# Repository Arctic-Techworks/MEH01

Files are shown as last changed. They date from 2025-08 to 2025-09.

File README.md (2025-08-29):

# **MEH01 replacement encoder for EVQWGD001**
 This is a very low cost (~ 1USD) full replacement for EVQWGD001 horizontal encoder. Project comes with all STL/STEP files for printing and incorporation into projects. It has the same base size as EVQWGD001 but due to different mounting mechanisms it won't "lock" into the EWQ* socket even though it fits. There are special openings in MEH01 socket where the encoder can "clip-in". 

Two versions are provided. With and without switch.

## **KiCAD** symbol, footprint and 3D model is also available (untested), check my [KiCad Library](https://github.com/EverydayErgo/KiCAD)

||||||
|--|--|--|--|--|
||
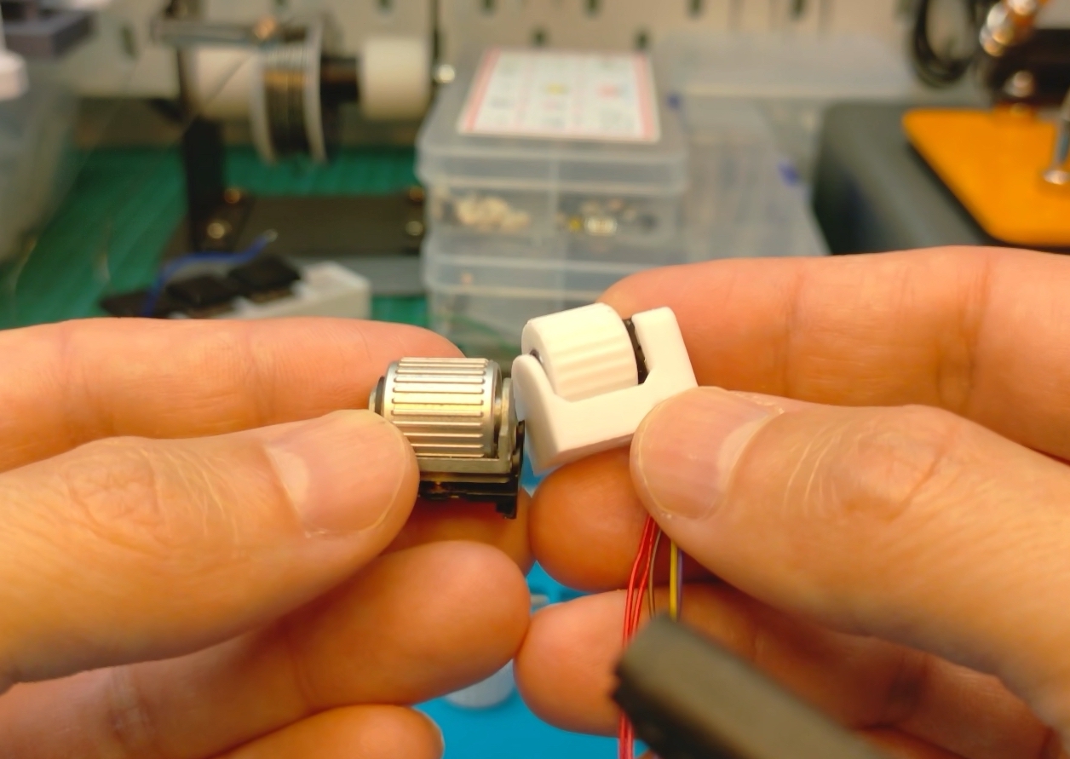
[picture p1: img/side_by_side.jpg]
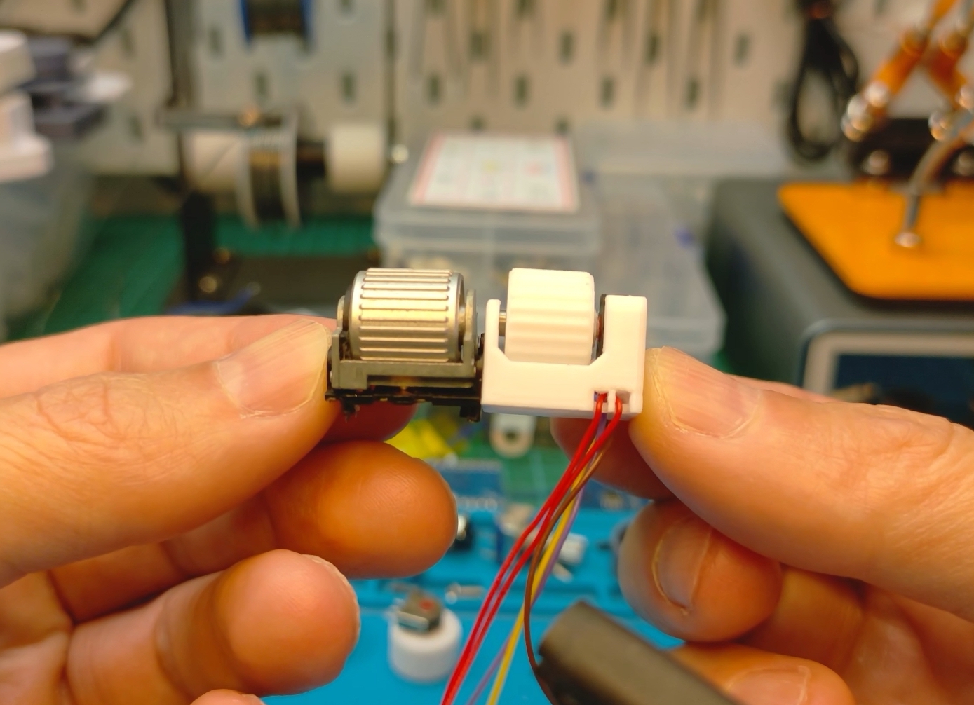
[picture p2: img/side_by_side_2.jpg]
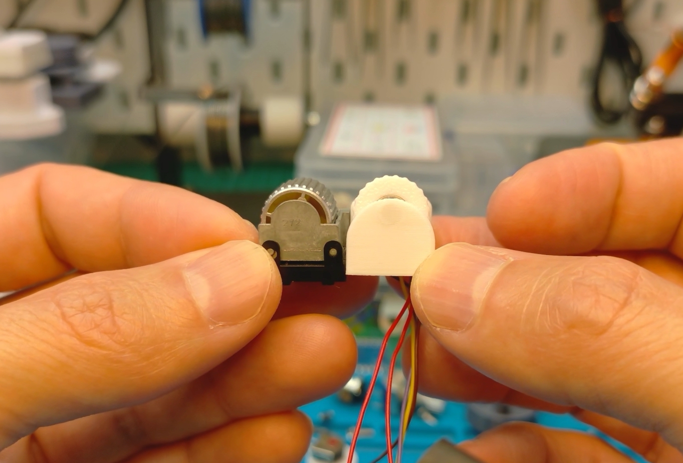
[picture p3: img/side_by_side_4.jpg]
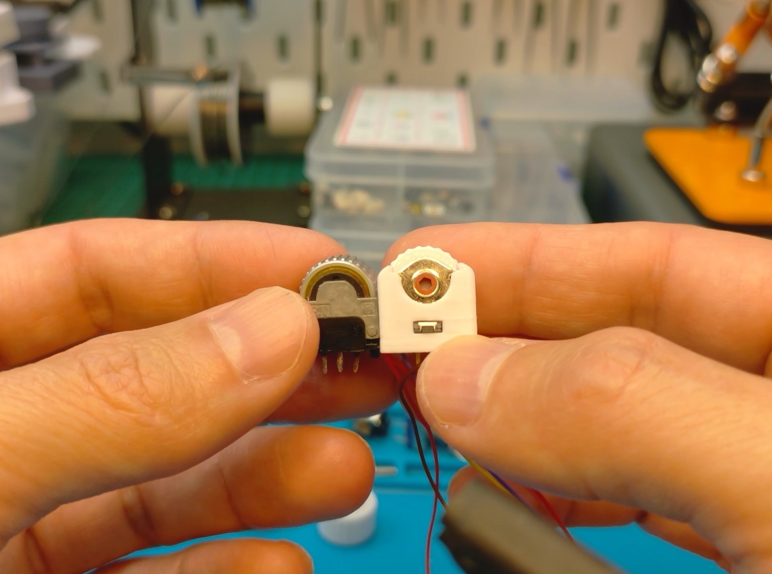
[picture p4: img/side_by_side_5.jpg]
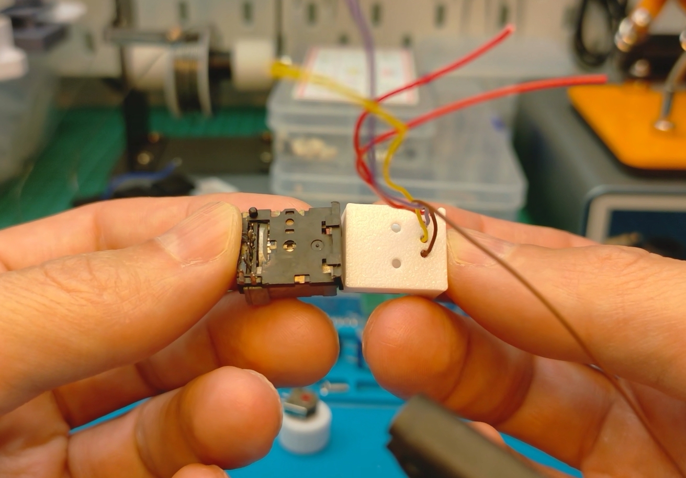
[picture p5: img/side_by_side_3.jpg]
||||||

|BOM|||
|--|--|--|
|**Item**|**Dimensions**|**Count**|
|[Kailh mouse encoder](img/kailh_1.png)|5mm|1|
|[MR63 RC Bearings (used in RC cars etc)](img/bearings_zzr.jpeg)|(M3)3mm x 6mm x 2mm|1|
|[Metal pin (bearing dowel)](img/metal_pin_1.jpg)|(M3)3mm x 6mm|1|
|[Tactile Push button](img/switch_1.jpg)|3mm x 4mm x 2mm|1|
|[AWG 30 Wire (best multi color)](img/wire_awg_30_1.jpg)||1|

Notice that the tactile switch has 1 leg, there's also version with 2 legs, this might be harder to solder wire to.

|STL||
|--|--|
|Item|Description|
|[Housing (switch)](stl/encoder_switch.stl)|Housing for the encoder with tactile switch|
|[Housing (no switch)](stl/encoder_no_switch.stl)|Housing for the encoder without switch|
|[Roller](stl/roller.stl)|Roller wheel|

**Print with PETG with 0.4mm nozzle. For the roller use support.**

|STEP||
|--|--|
|Item|Description|
|[Housing (switch)](step/encoder_switch.stp)|Housing for the encoder with tactile switch|
|[Housing (no switch)](step/encoder_no_switch.stp)|Housing for the encoder without switch|
|[Roller](step/roller.stp)|Roller wheel|
|[MEH01](step/MEH01.stp)|Full assembly|
|[Socket PCB](step/socket_pcb.stp)|Socket/mount for PCB|
|[Socket](step/socket.stp)|Socket/mount for keyboard plate|

Use these files to incorporate MEH01 into your CAD project.

## How to assemble
There are few live streams where I am building MEH01:
- [[Let's build #42] - Chordie, chording split mechanical keyboard you shouldn't be scared of
](https://youtu.be/GDPil8_5gyE?t=2537)
- [[Let's build #45] - Chordie, chording split mechanical keyboard you shouldn't be scared of
](https://youtu.be/FPBJ9f71gYo?t=291)

|||||
|--|--|--|--|
||
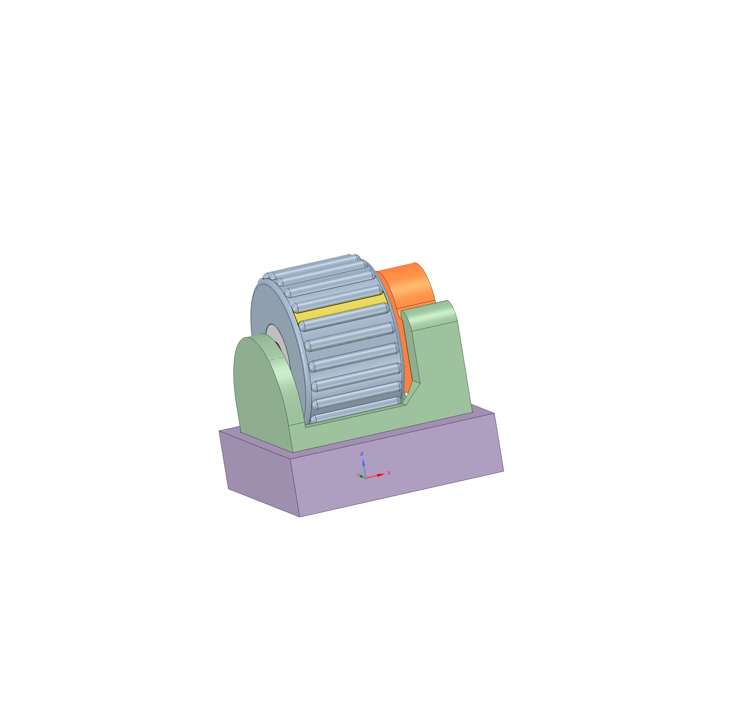
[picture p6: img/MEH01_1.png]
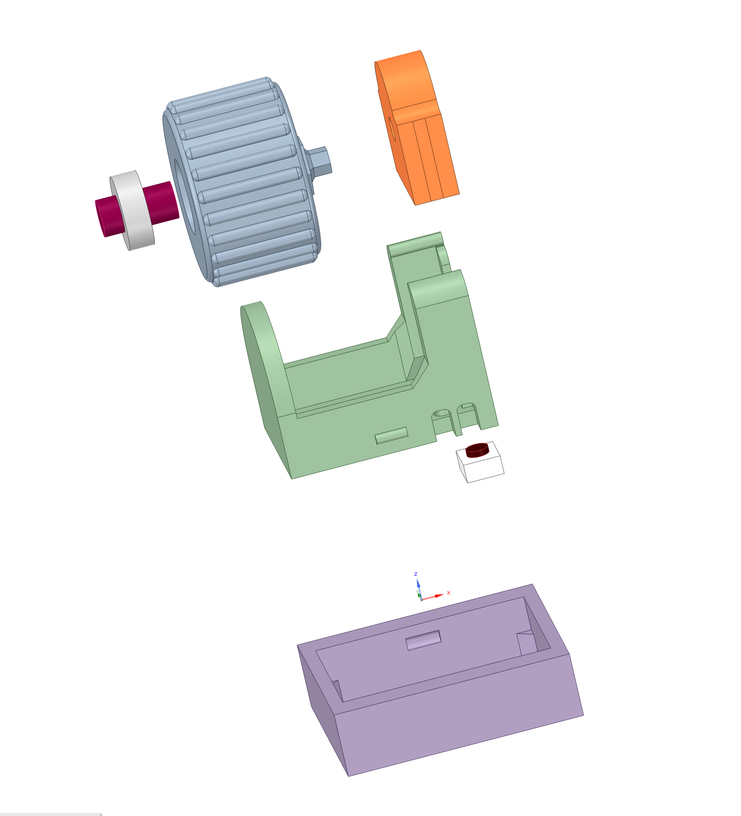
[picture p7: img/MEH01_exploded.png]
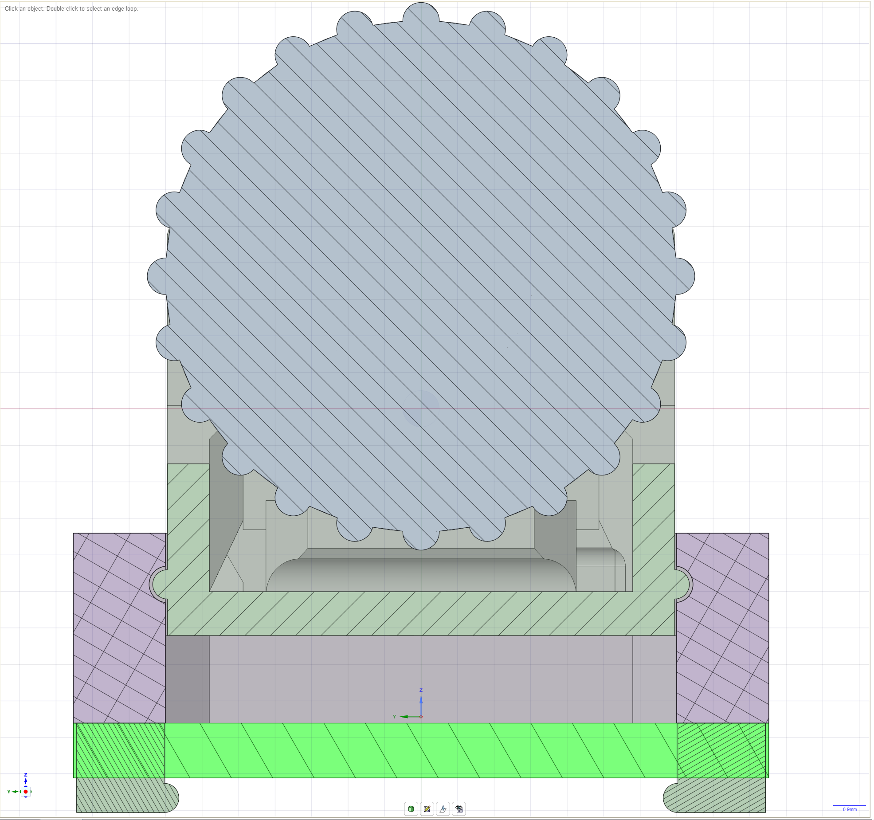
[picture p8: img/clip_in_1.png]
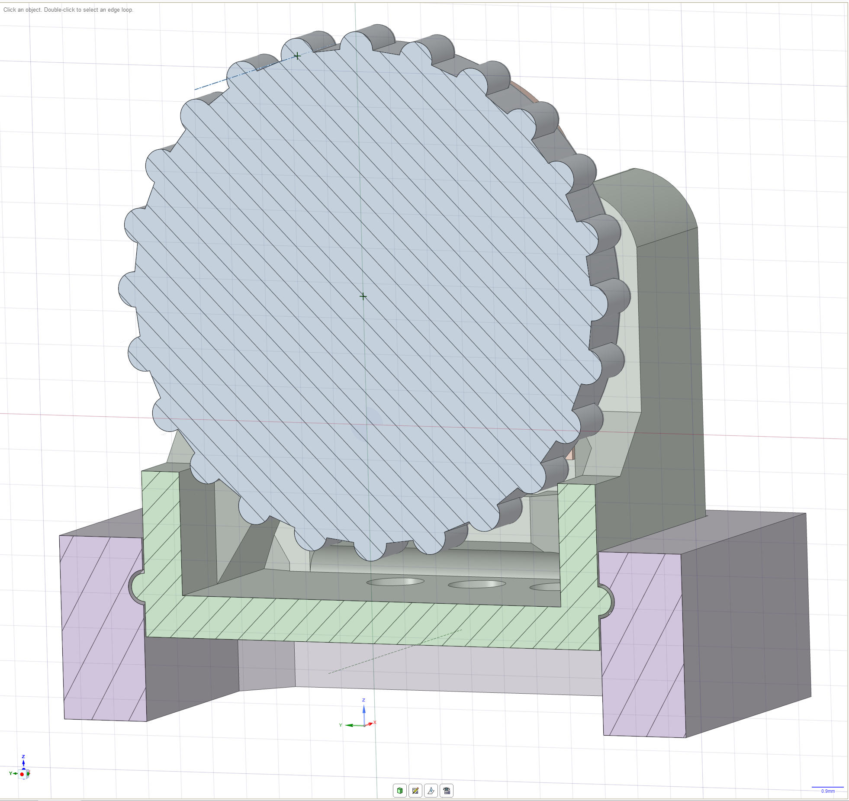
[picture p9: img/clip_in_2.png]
|||||

For the version with tactile switch, solder AWG 30 wire to the switch terminals and route it. There's a canal under the switch to route left terminal, both should go via two holes on the side of the housing.

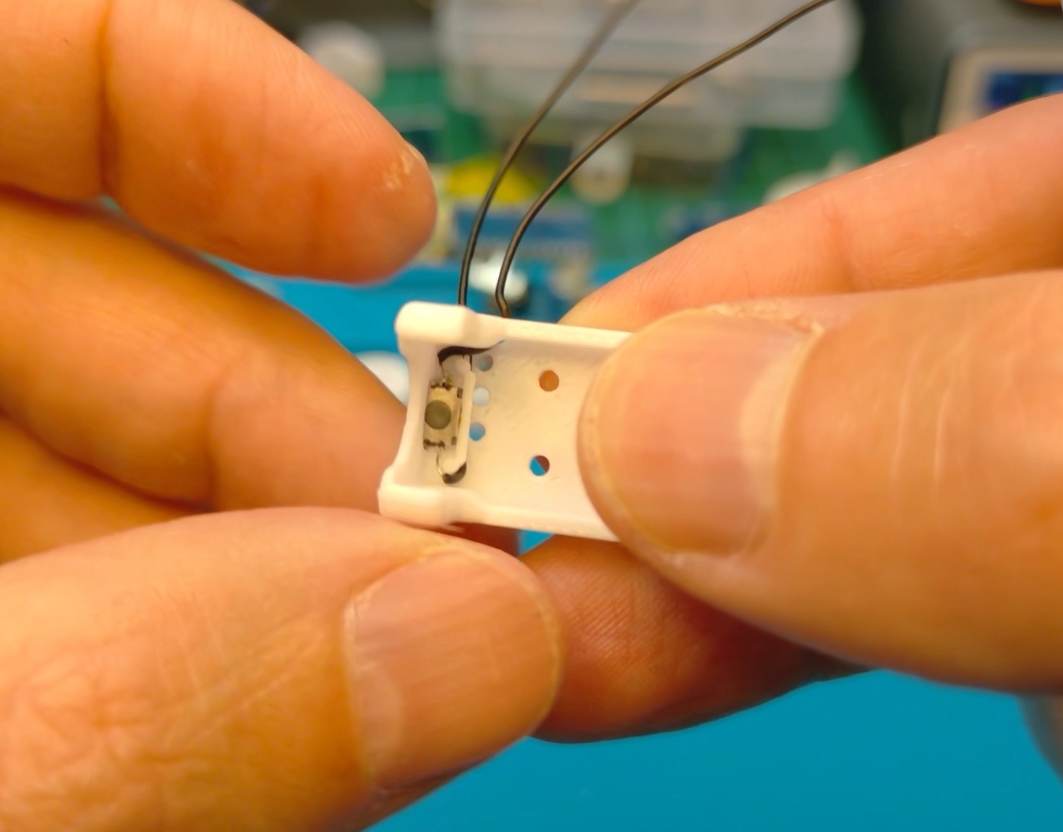
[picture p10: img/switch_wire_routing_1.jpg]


Push the bearing and metal pin inside the roller.

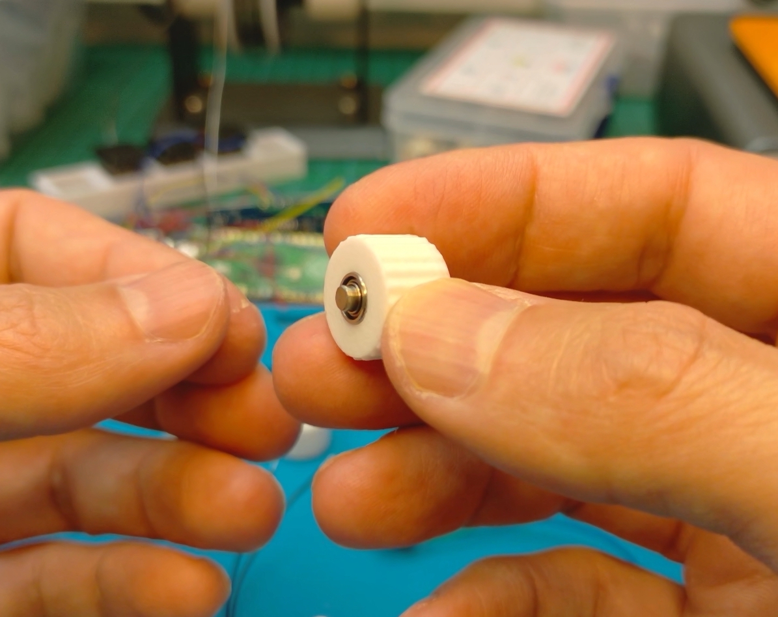
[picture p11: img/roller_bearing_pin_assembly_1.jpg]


Clip side mounting legs from the Kailh mouse encoder.

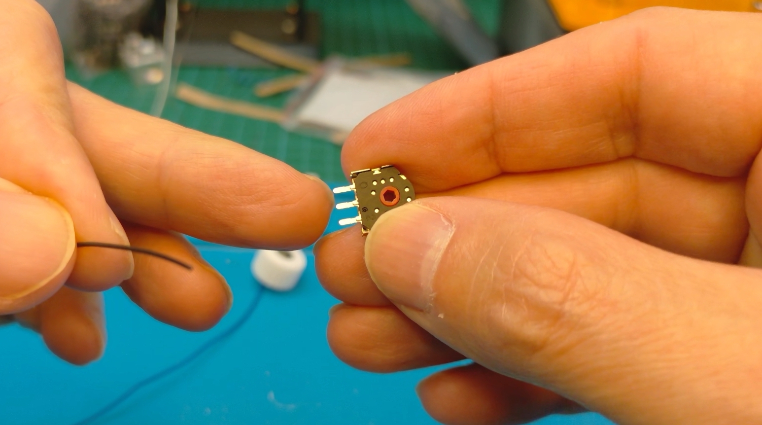
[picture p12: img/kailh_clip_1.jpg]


Solder wires to Kailh encoder terminals. Route them through the holes on the bottom of the housing. Back (black part) of the encoder should be facing the roller. Attach the roller. Take notice of encoder terminals, Com/A/B pins are in different positions as compared EVQWGD001, check the schematic below. Slide the encoder into the housing, you might want to start at 45 deg angle and then make you way. Check the stream if unshure on how to slide it in. 

|||||
|--|--|--|--|
||
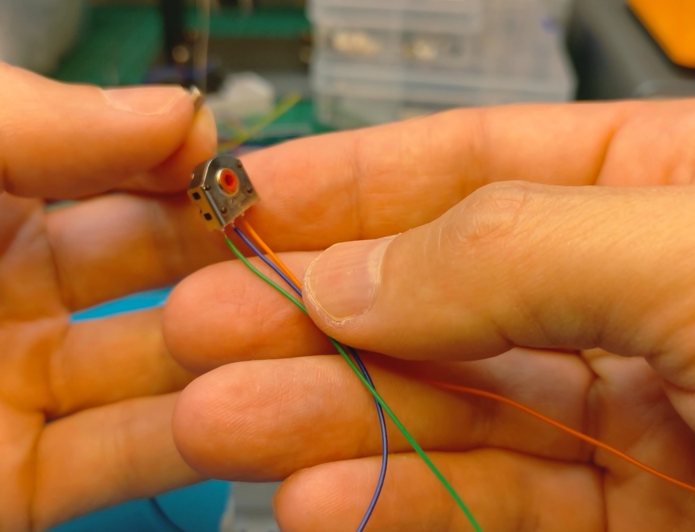
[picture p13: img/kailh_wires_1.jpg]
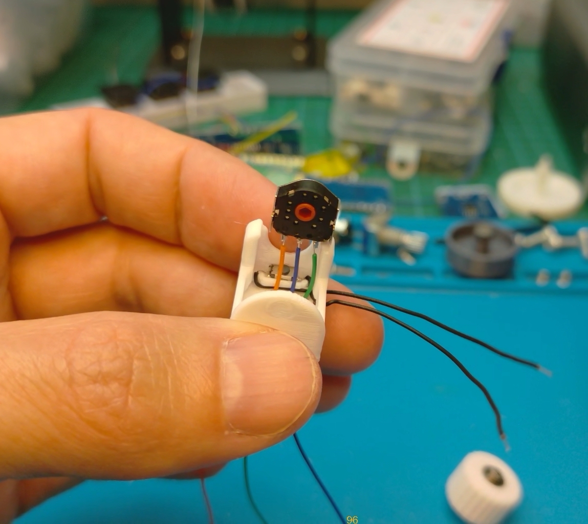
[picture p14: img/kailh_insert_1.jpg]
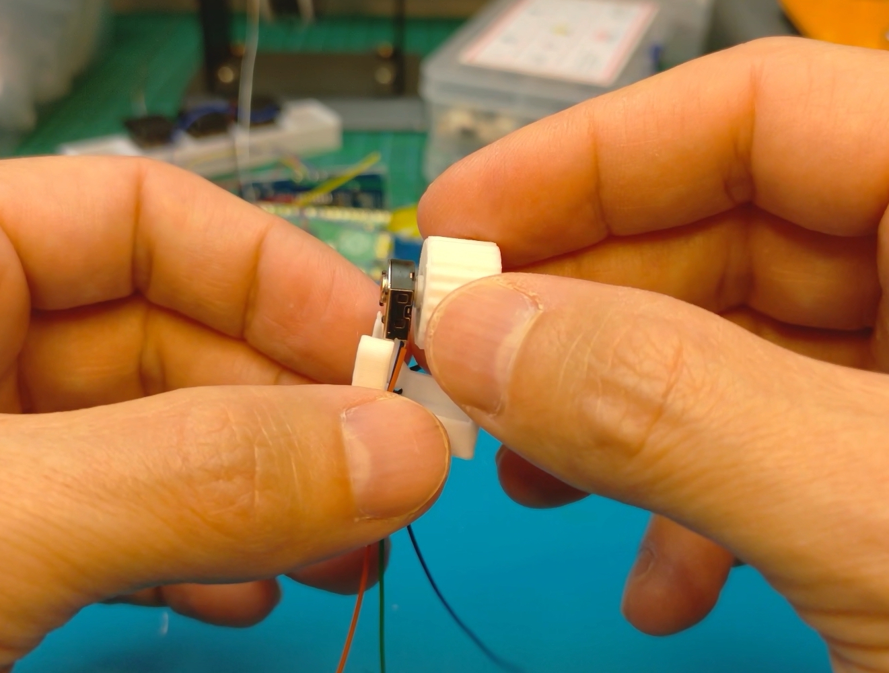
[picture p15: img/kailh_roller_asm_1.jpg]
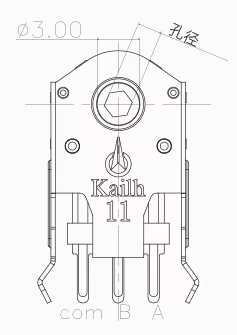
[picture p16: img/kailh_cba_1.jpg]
|||||

There's a tiny clip inside the socket that should hold the housing quite well.

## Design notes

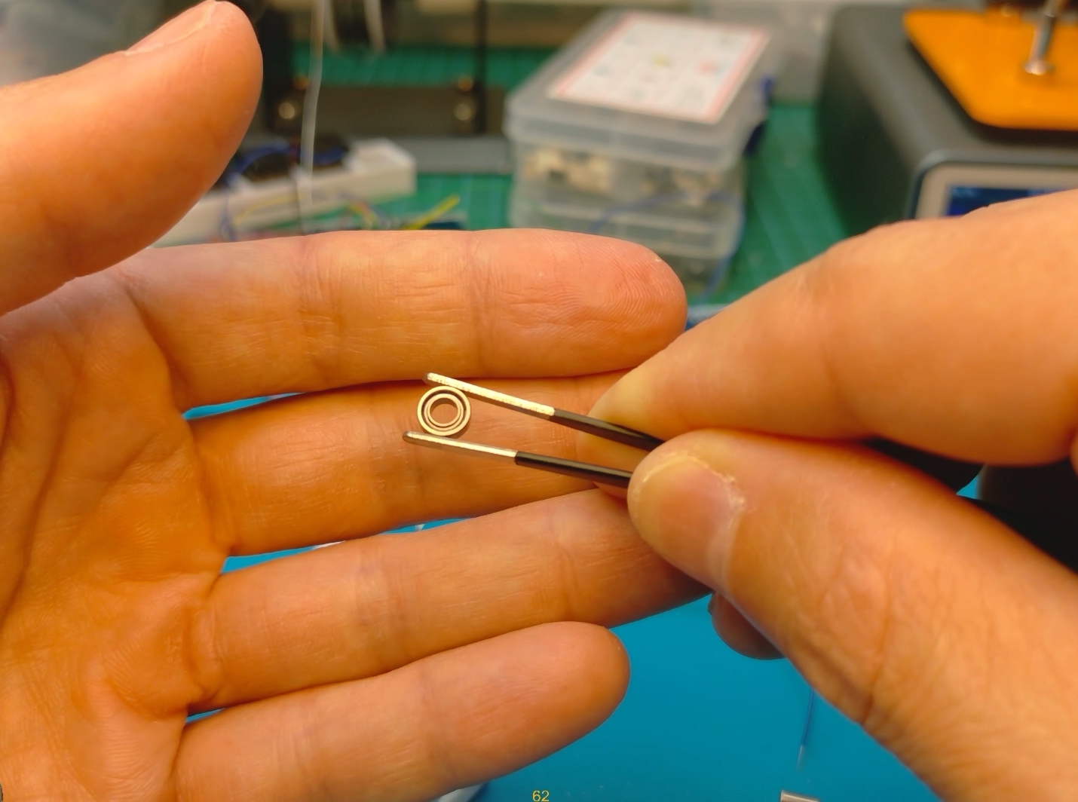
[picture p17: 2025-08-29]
img/bearing_zzr.jpg

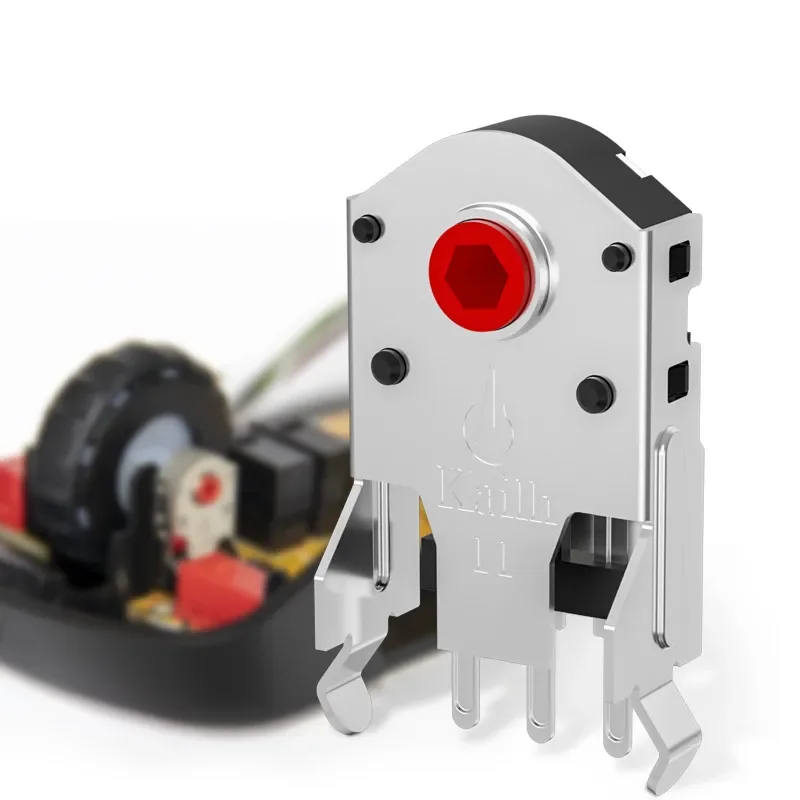
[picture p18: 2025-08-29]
img/kailh_1.png

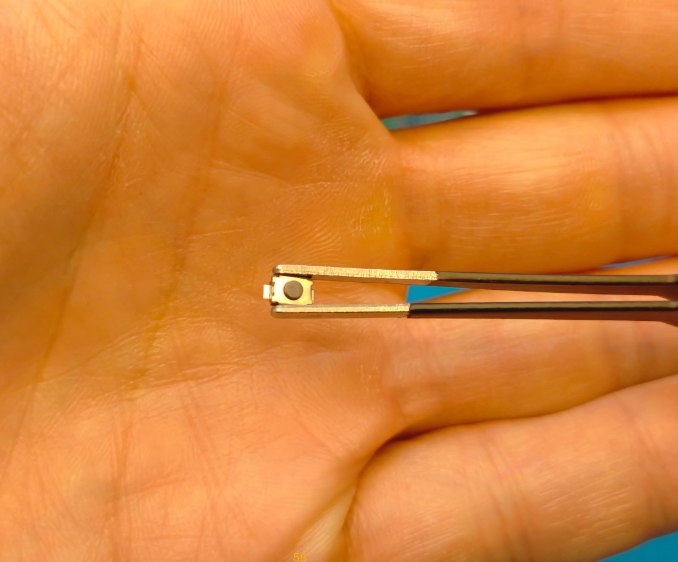
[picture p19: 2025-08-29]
img/switch_1.jpg

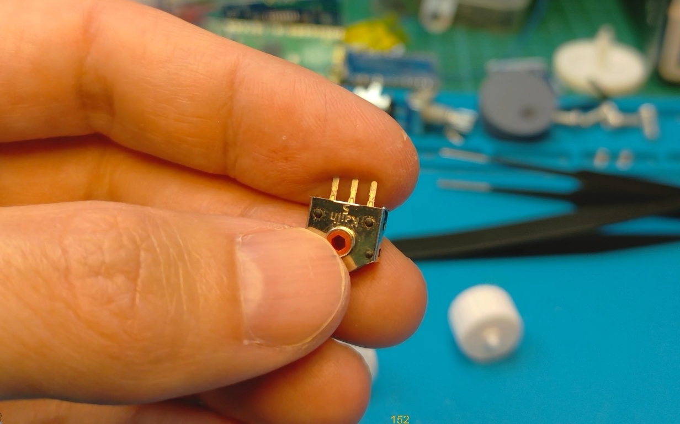
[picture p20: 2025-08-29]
img/kailh_cut_1.jpg

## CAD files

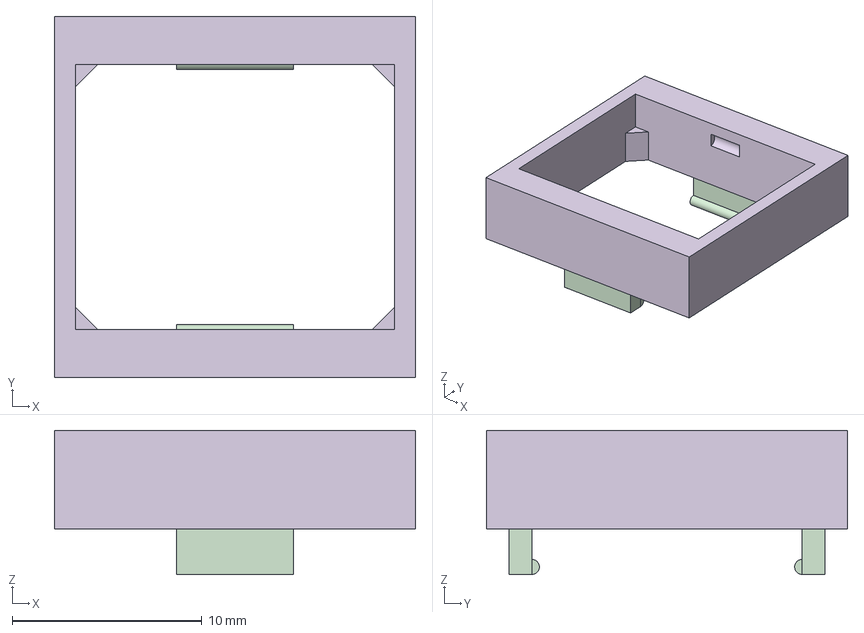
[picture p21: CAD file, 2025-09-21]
step/socket_pcb.stp
19.0 x 19.1 x 7.60 mm
Encoders.7
Socket PCB Geometry
Hooks

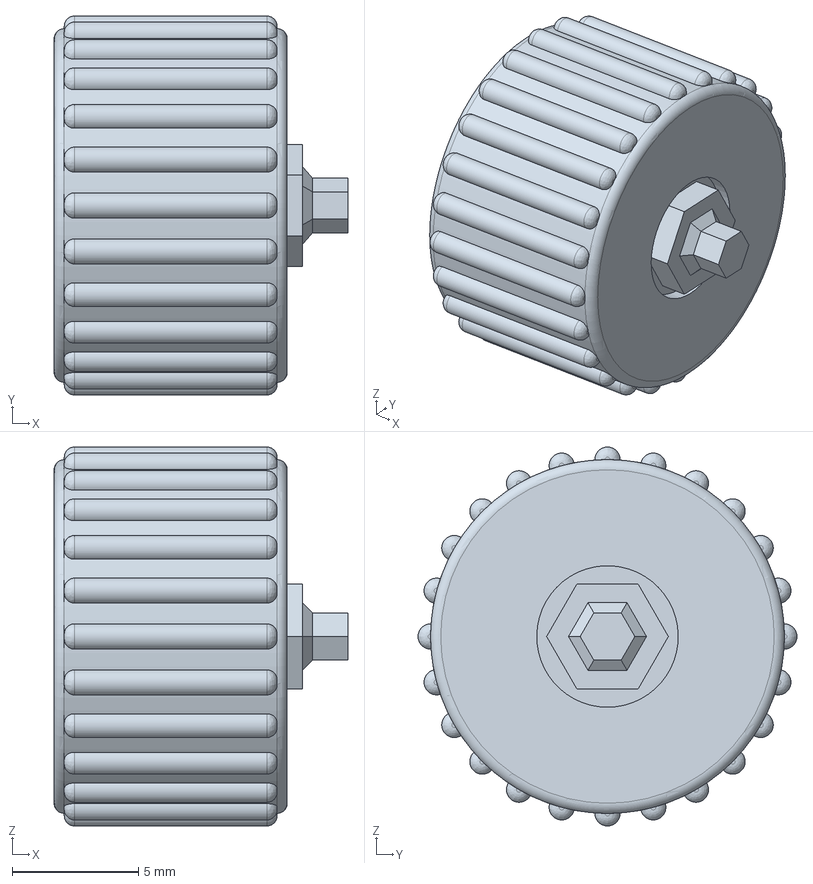
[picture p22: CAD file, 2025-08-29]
step/roller.stp
11.6 x 15.0 x 15.0 mm

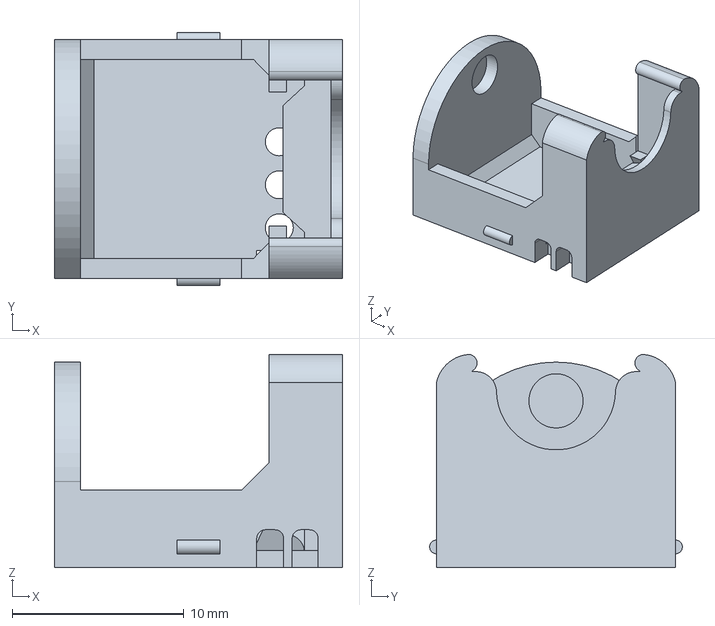
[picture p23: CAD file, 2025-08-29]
step/encoder_no_switch.stp
16.8 x 14.7 x 12.4 mm

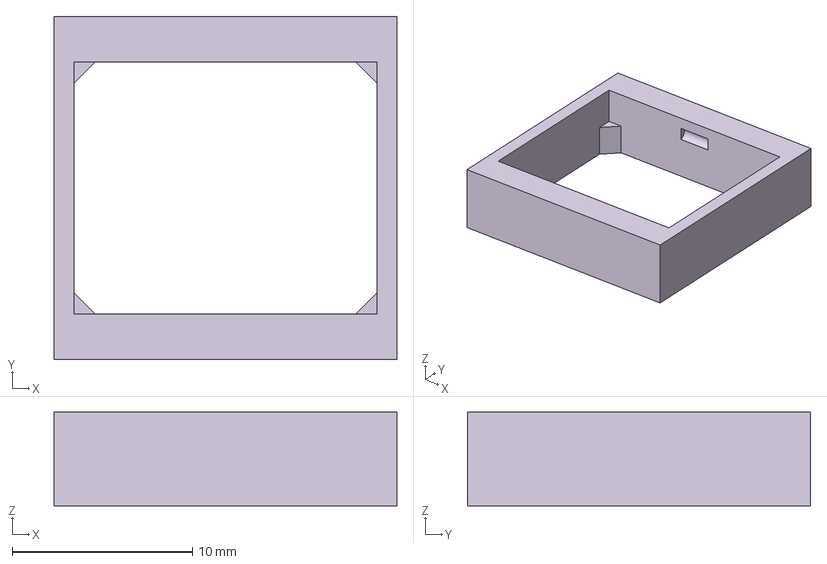
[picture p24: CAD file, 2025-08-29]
step/socket.stp
19.0 x 19.1 x 5.20 mm

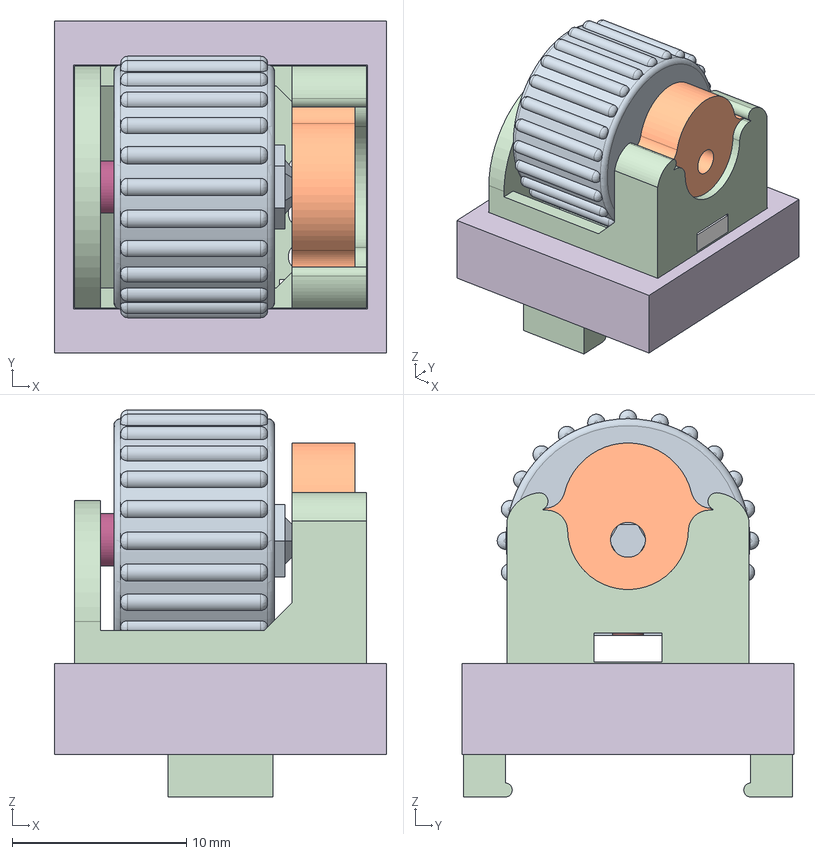
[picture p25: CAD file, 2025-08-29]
step/MEH01.stp
19.0 x 19.1 x 22.2 mm
With switch
Roller R72
Socket PCB Geometry
Hooks
Encoder 5mm Kailh
Bearing
Metal pin
Switch

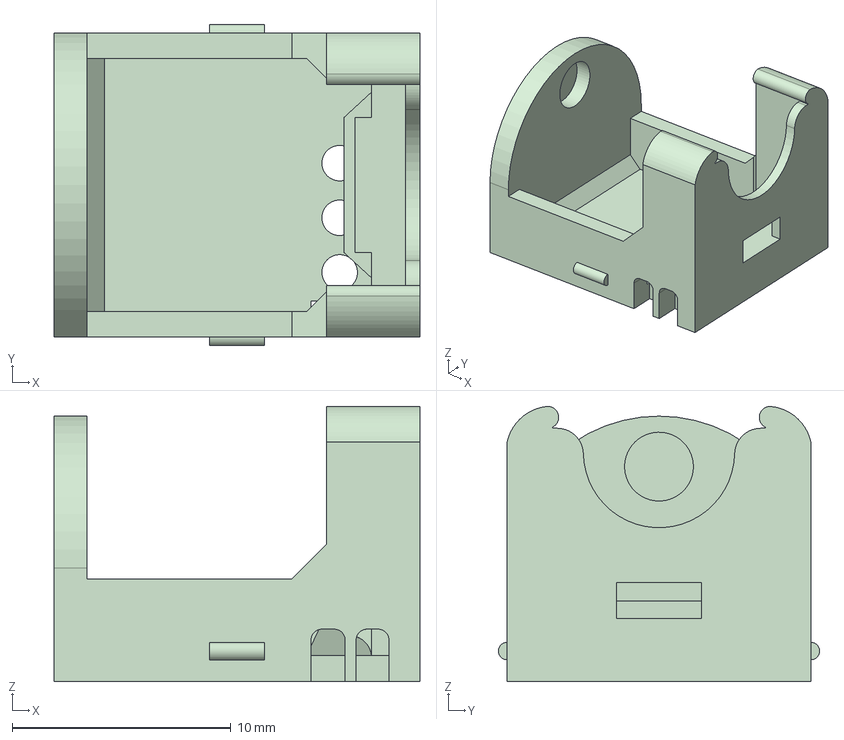
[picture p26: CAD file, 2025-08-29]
step/encoder_switch.stp
16.7 x 14.7 x 12.6 mm

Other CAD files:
stl/encoder_no_switch.stl
stl/encoder_switch.stl

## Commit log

2025-08-29 Initial commit
    MEH01 horizontal encoder, replacement for EVQWGD001
    [MEH01.stp, encoder_no_switch.stl, encoder_no_switch.stp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]
2025-09-21 Socket PCB update
    Changes to accommodate for tight fit with PCB footprint.
    [socket_pcb.stp]
